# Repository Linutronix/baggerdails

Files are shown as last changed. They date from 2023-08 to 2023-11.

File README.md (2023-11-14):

<!-- SPDX-FileCopyrightText: 2023 Linutronix GmbH <info@linutronix.de> -->
<!-- SPDX-License-Identifier: CERN-OHL-S-2.0 -->


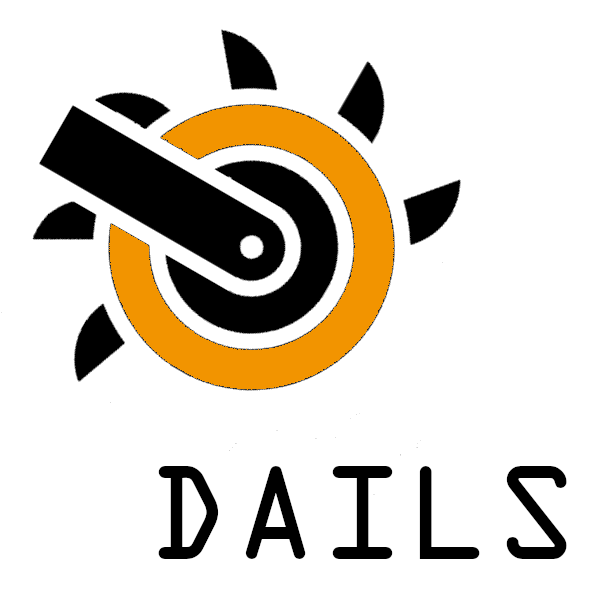
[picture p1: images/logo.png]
baggerdails logo


# baggerdails - A RPi HAT for a trade fair demo

The baggerdails RPi HAT is a small PCB containing 14 LEDs, a 256k serial
EEPROM, an ATECC608 Security Verification / Encryption IC, two SPI display
connectors and last but not least an USB serial converter attached to a
full-size 40W GPIO connector as described in the
[ADD-ON BOARDS AND HATs specification](https://github.com/raspberrypi/hats).

## License rules

baggerdails is provided under the terms of the CERN-OHL-S license version 2
as provided in the LICENSES/CERN-OHL-S-2.0 file.

Instead of adding license boilerplates to the individual files, baggerdails
uses SPDX license identifiers, which are machine parseable and considered
legaly equivalent.

The SPDX license identifier in baggerdails shall be added at the first possible
line in a file which can contain a comment. This is normally the first line
except for scripts. Scripts require the #!PATH_TO_INTERPRETER tag in the
first line; place the SPDX identifier into the second line.

The SPDX license identifier is added in form of a comment.

## Copyright and License

Copyright Linutronix GmbH 2023.

This source describes Open Hardware and is licensed under the CERN-OHL-S v2.
You may redistribute and modify this source and make products using it
under the terms of the CERN-OHL-S v2 (https://ohwr.org/cern_ohl_s_v2.txt).

This source is distributed WITHOUT ANY EXPRESS OR IMPLIED WARRANTY,
INCLUDING OF MERCHANTABILITY, SATISFACTORY QUALITY AND FITNESS FOR A
PARTICULAR PURPOSE.

Please see the CERN-OHL-S v2 for applicable conditions.

Source location: https://github.com/linutronix/baggerdails

As per CERN-OHL-S v2 section 4, should You produce hardware based
on this source, You must where practicable maintain the Source Location
visible on the external case of the baggerdails or other products you make
using this source.

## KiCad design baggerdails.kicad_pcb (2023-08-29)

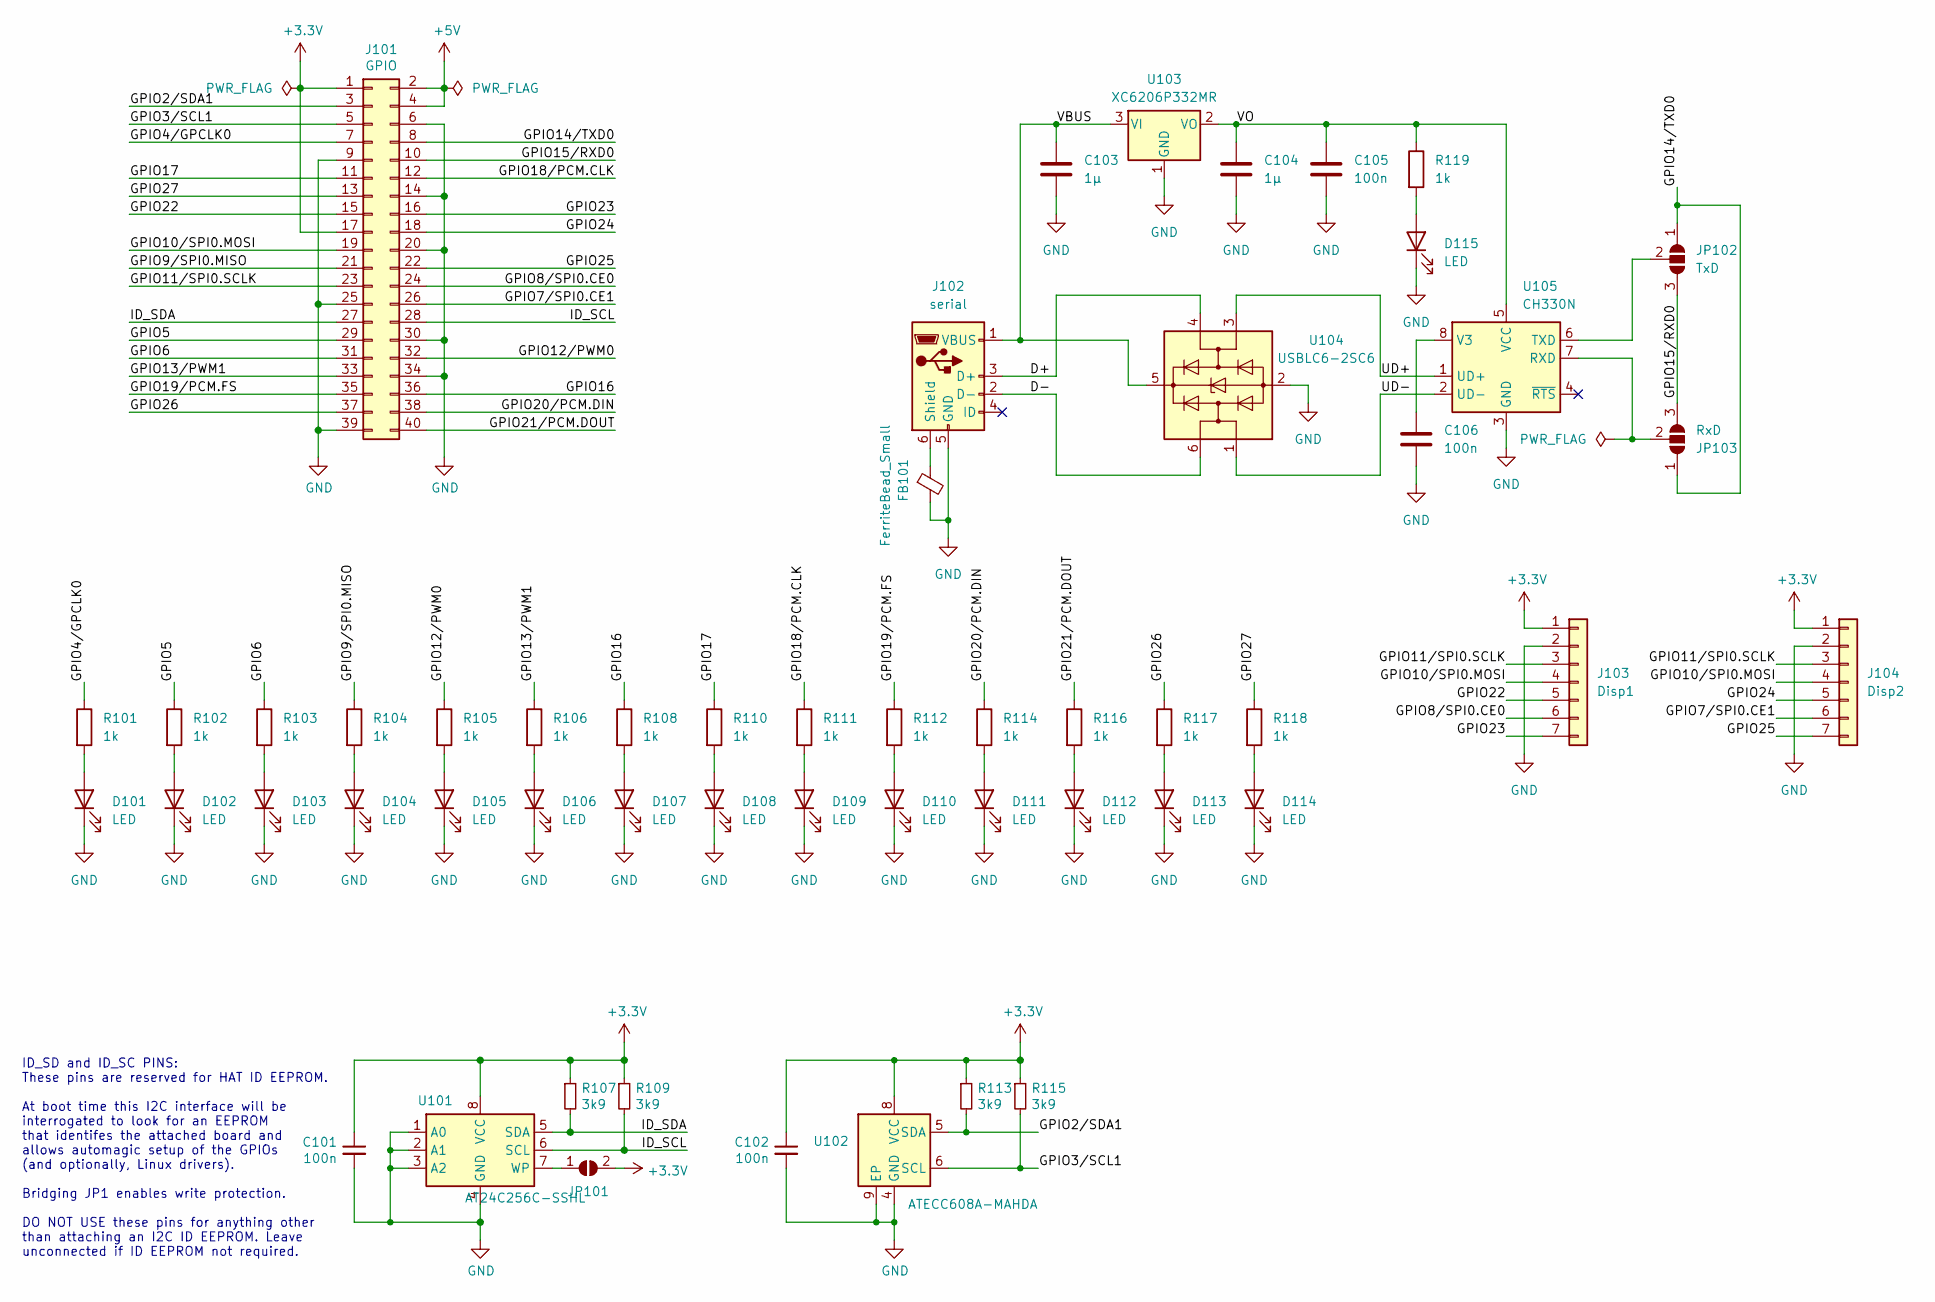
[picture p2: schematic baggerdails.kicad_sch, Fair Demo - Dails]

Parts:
C101, C102, C105, C106: 100n; C_0402_1005Metric; mpn GRM155R71H104KE14D; lcsc# C77020
C103, C104: 1µ; C_0805_2012Metric; mpn GRT21BR71H105KE01L; lcsc# C701194
D101, D102, D103, D104, D105, D106, D107, D108, D109, D110, D111, D112, D113, D114, D115: LED; LED_0603_1608Metric; mpn 19-217/BHC-ZL1M2RY/3T; lcsc# C72041
FB101: FerriteBead_Small; L_0402_1005Metric; mpn BLM15AG121SN1D; lcsc# C85812
J101: GPIO; PinSocket_2x20_P2.54mm_Vertical; mpn DS1023-2*20S21
J102: serial; USB_Micro-B_Molex-105017-0001; mpn 1050171001; digikey# WM11262CT-ND
J103: Disp1; PinSocket_1x07_P2.54mm_Vertical; mpn DS1023-1*7S21
J104: Disp2; PinSocket_1x07_P2.54mm_Vertical; mpn DS1023-1*7S21
JP101: ID_WP; SolderJumper-2_P1.3mm_Open_Pad1.0x1.5mm; mpn DNP
JP102: TxD; SolderJumper-3_P1.3mm_Open_Pad1.0x1.5mm_NumberLabels; mpn DNP
JP103: RxD; SolderJumper-3_P1.3mm_Open_Pad1.0x1.5mm_NumberLabels; mpn DNP
R101, R102, R103, R104, R105, R106, R108, R110, R111, R112, R114, R116, R117, R118, R119: 1k; R_0402_1005Metric; mpn RC0402JR-071KL; digikey# 311-1.0KJRCT-ND
R107, R109, R113, R115: 3k9; R_0402_1005Metric; mpn AF0402FR-073K9L; lcsc# C144037
U101: AT24C256C-SSHL; SOIC-8_3.9x4.9mm_P1.27mm; mpn AT24C256C-SSHL-T; lcsc# C6482
U102: ATECC608A-MAHDA; DFN-8-1EP_3x2mm_P0.5mm_EP1.3x1.5mm; mpn ATECC608A-MAHDA-T; lcsc# C616909
U103: XC6206P332MR; SOT-23-3; mpn XC6206P332MR; lcsc# C2897477
U104: USBLC6-2SC6; SOT-23-6; mpn USBLC6-2SC6; lcsc# C7519
U105: CH330N; SOIC-8_3.9x4.9mm_P1.27mm; mpn CH330N; lcsc# C108996

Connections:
+3.3V: C101.1, C102.1, J101.1, J101.17, J103.1, J104.1, JP101.2 (B), R107.1, R109.1, R113.1, R115.1, U101.8 (VCC), U102.8 (VCC)
+5V: J101.2, J101.4
/D+: J102.3 (D+), U104.4 (I/O2)
/D-: J102.2 (D-), U104.6 (I/O1)
/GPIO2/SDA1: J101.3, R113.2, U102.5 (SDA)
/GPIO3/SCL1: J101.5, R115.2, U102.6 (SCL)
/GPIO4/GPCLK0: J101.7, R101.1
/GPIO5: J101.29, R102.1
/GPIO6: J101.31, R103.1
/GPIO7/SPI0.CE1: J101.26, J104.6
/GPIO8/SPI0.CE0: J101.24, J103.6
/GPIO9/SPI0.MISO: J101.21, R104.1
/GPIO10/SPI0.MOSI: J101.19, J103.4, J104.4
/GPIO11/SPI0.SCLK: J101.23, J103.3, J104.3
/GPIO12/PWM0: J101.32, R105.1
/GPIO13/PWM1: J101.33, R106.1
/GPIO14/TXD0: J101.8, JP102.1 (A), JP103.1 (A)
/GPIO15/RXD0: J101.10, JP102.3 (B), JP103.3 (B)
/GPIO16: J101.36, R108.1
/GPIO17: J101.11, R110.1
/GPIO18/PCM.CLK: J101.12, R111.1
/GPIO19/PCM.FS: J101.35, R112.1
/GPIO20/PCM.DIN: J101.38, R114.1
/GPIO21/PCM.DOUT: J101.40, R116.1
/GPIO22: J101.15, J103.5
/GPIO23: J101.16, J103.7
/GPIO24: J101.18, J104.5
/GPIO25: J101.22, J104.7
/GPIO26: J101.37, R117.1
/GPIO27: J101.13, R118.1
/ID_SCL: J101.28, R109.2, U101.6 (SCL)
/ID_SDA: J101.27, R107.2, U101.5 (SDA)
/UD+: U104.3 (I/O2), U105.1 (UD+)
/UD-: U104.1 (I/O1), U105.2 (UD-)
/VBUS: C103.1, J102.1 (VBUS), U103.3 (VI), U104.5 (VBUS)
/VO: C104.1, C105.1, R119.1, U103.2 (VO), U105.5 (VCC)
GND: C101.2, C102.2, C103.2, C104.2, C105.2, C106.2, D101.1 (K), D102.1 (K), D103.1 (K), D104.1 (K), D105.1 (K), D106.1 (K), D107.1 (K), D108.1 (K), D109.1 (K), D110.1 (K), D111.1 (K), D112.1 (K), D113.1 (K), D114.1 (K), D115.1 (K), FB101.2, J101.6, J101.9, J101.14, J101.20, J101.25, J101.30, J101.34, J101.39, J102.5 (GND), J103.2, J104.2, U101.1 (A0), U101.2 (A1), U101.3 (A2), U101.4 (GND), U102.4 (GND), U102.9 (EP), U103.1 (GND), U104.2 (GND), U105.3 (GND)
unnamed: D101.2 (A), R101.2
unnamed: D102.2 (A), R102.2
unnamed: D103.2 (A), R103.2
unnamed: D104.2 (A), R104.2
unnamed: D105.2 (A), R105.2
unnamed: D106.2 (A), R106.2
unnamed: D107.2 (A), R108.2
unnamed: D108.2 (A), R110.2
unnamed: D109.2 (A), R111.2
unnamed: D110.2 (A), R112.2
unnamed: D111.2 (A), R114.2
unnamed: D112.2 (A), R116.2
unnamed: D113.2 (A), R117.2
unnamed: D114.2 (A), R118.2
unnamed: D115.2 (A), R119.2
unnamed: FB101.1, J102.6 (Shield)
unnamed: JP101.1 (A), U101.7 (WP)
unnamed: JP102.2 (C), U105.6 (TXD)
unnamed: JP103.2 (C), U105.7 (RXD)
unnamed: C106.1, U105.8 (V3)

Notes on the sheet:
ID_SD and ID_SC PINS: These pins are reserved for HAT ID EEPROM. At boot time this I2C interface will be interrogated to look for an EEPROM that identifes the attached board and allows automagic setup of the GPIOs (and optionally, Linux drivers). Bridging JP1 enables write protection. DO NOT USE th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

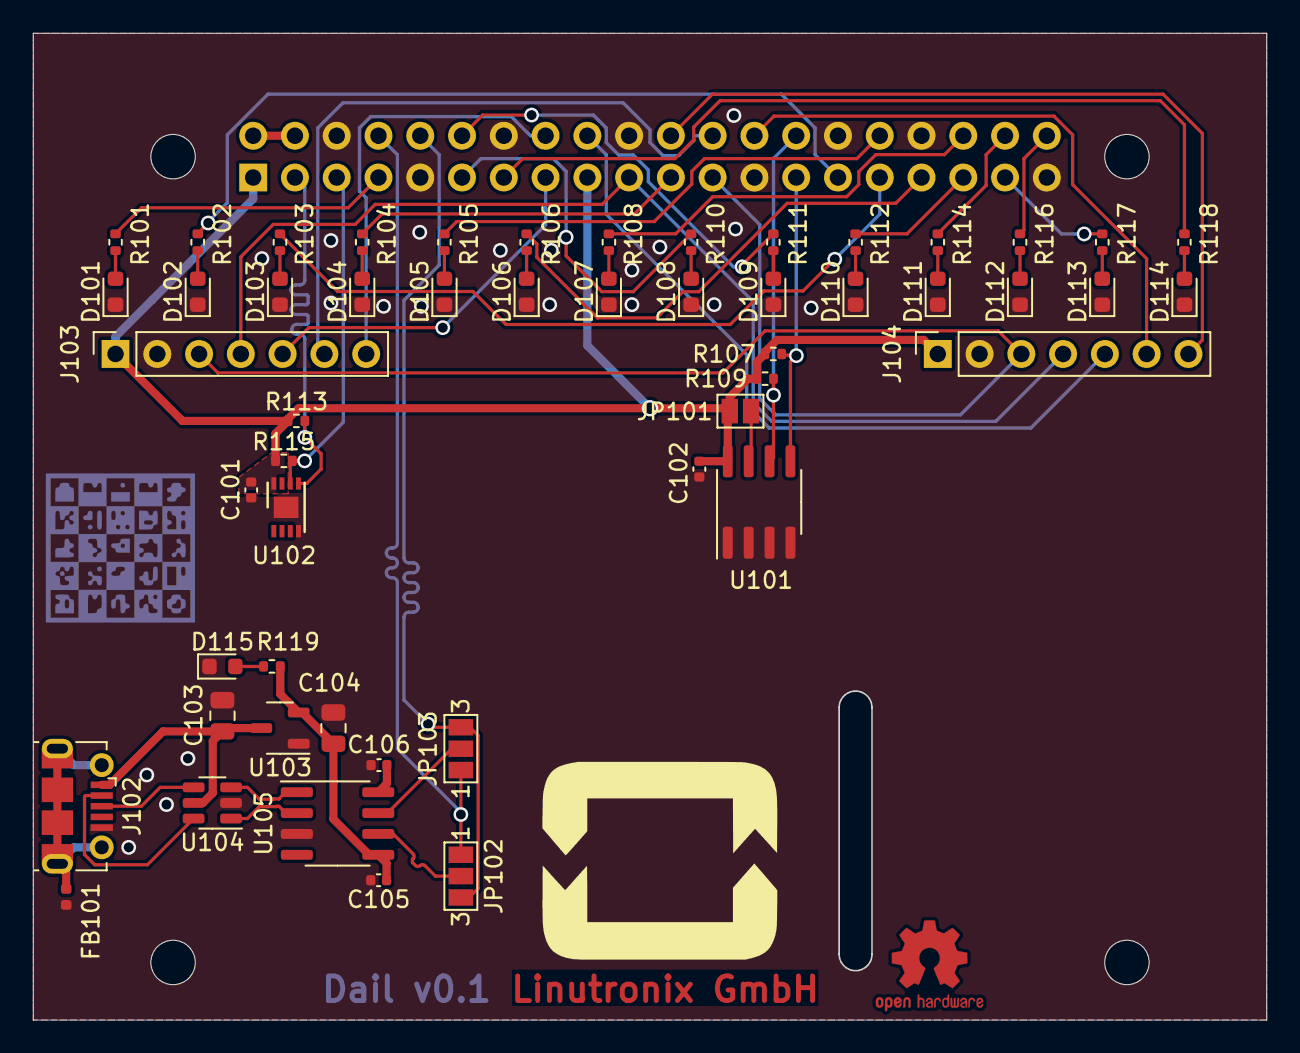
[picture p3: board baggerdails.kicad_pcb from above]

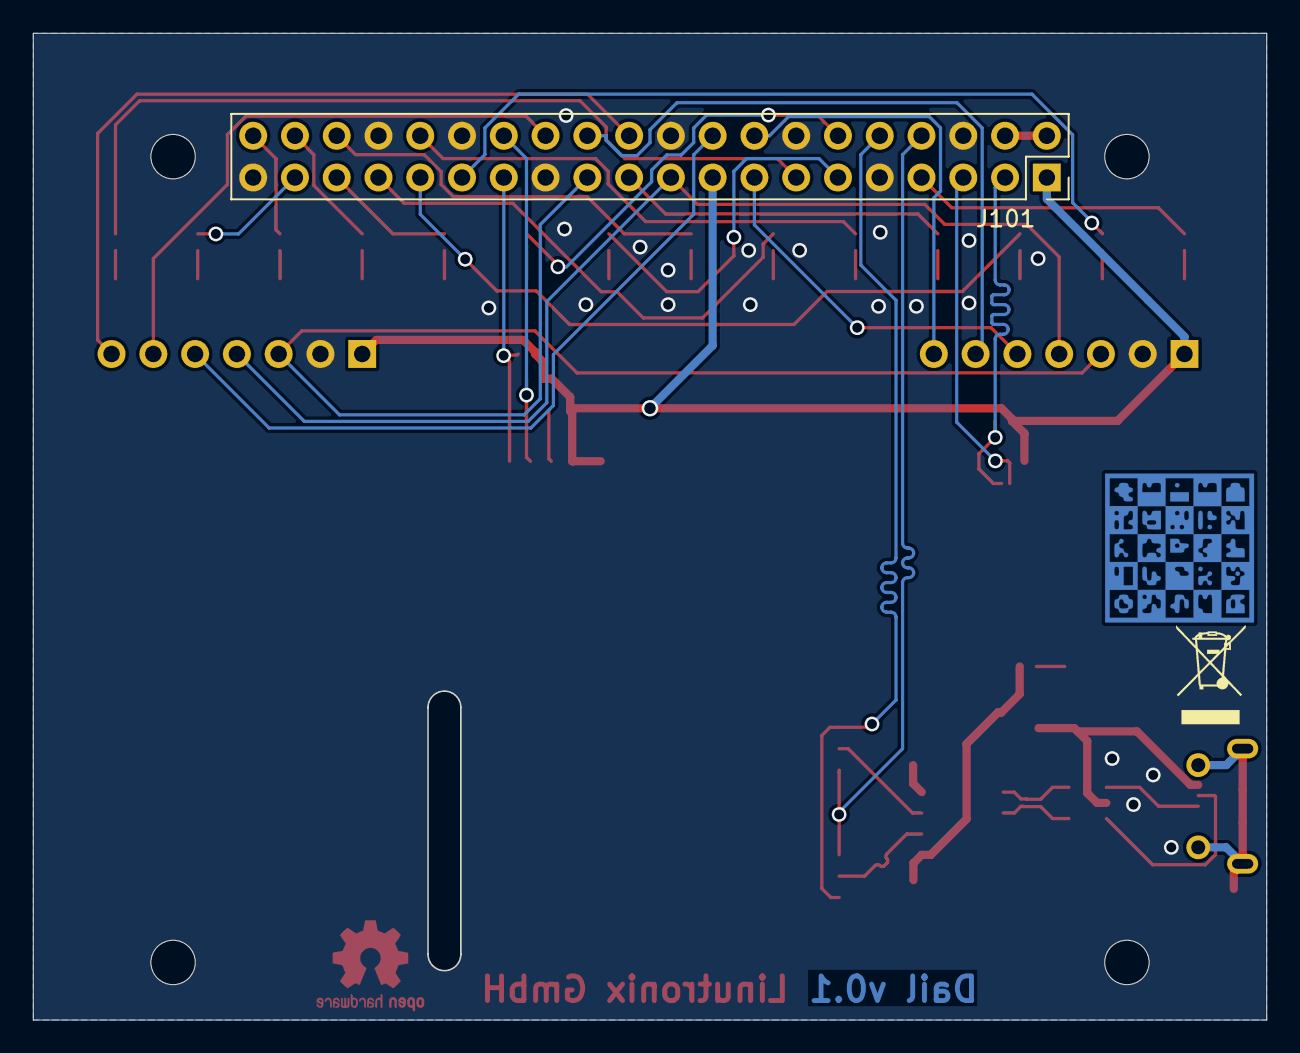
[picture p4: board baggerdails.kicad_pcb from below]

Board: 2 copper layers, 75.0 x 60.0 mm, 61 parts (3 on the bottom side), 57 nets.

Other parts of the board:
Eurovibes: LOGO
Linutronix: LOGO; linutronix
MH1, MH2, MH3, MH4: MountingHole_2.7mm_M2.5
OSHW: OSHW-Logo2_7.3x6mm_Copper
WEEE: WEEE-Logo_4.2x6mm_SilkScreen

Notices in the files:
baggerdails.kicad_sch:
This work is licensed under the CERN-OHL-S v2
